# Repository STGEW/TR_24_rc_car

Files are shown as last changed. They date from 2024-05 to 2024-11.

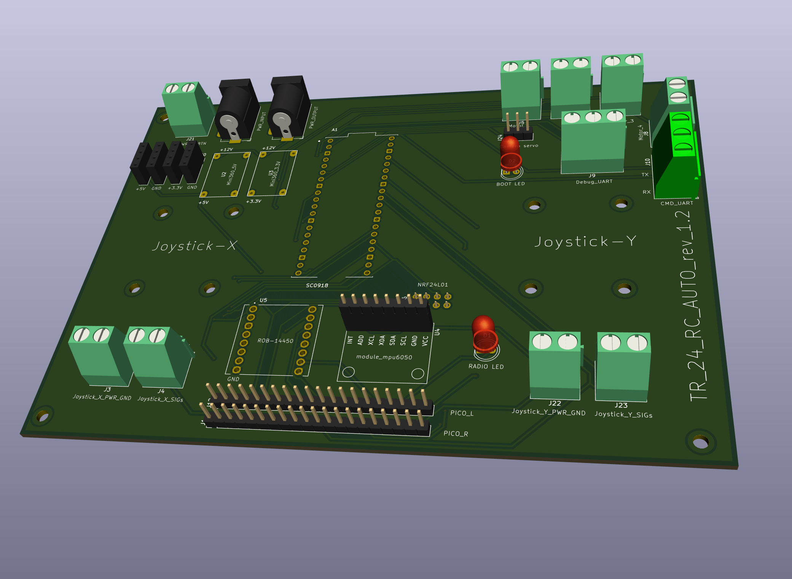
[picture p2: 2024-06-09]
pcb_design/pcb_rev_1_2_img_1.png

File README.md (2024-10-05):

# What's inside?
It's a project with a self build RC car. The project doesn't pretend to be a production ready, but is done for educational purposes.

It has two major parts - a car itself + remote controller.
The project covers:
1) a hardware design of the car and RC - PCB, components, etc
2) a software done in C (TBH it's C++, but only a tiny set of features was used) and in Micropython. They are interchangable and should work on the same set of the hardware.

# Car
A car is built on the platform ordered on the well known web site. The platform has frame done with plexiglass + 4 motos with wheels.
TBD - insert an image

# RC
RC is build with 2 joysticks. Each joystick can be moved in one direction (for the convenience).
TBD - insert an image

# Communication
Communication is done with 2 tranceivers via RF channel. A protocol is extremely simple.

# Freertos part
The code is written on C with Freertos OS. For technical details please check ./freertos_code/README.md

# BOM
Joysticks - KY-023 - 2 items
Battery for car - LiPo battery DC-12300 (12V 3000 mAh)
Batteries for RC - 4 AA type batteries. I'm using 4 Ni-MH accumulators. Can be recharged.
DC-DC converter - MINI-360 DC-DC buck converter (step down). You need 3 of them for converting input voltage to 5V or 3.3V
Motor driver - tb6612fng motor driver
MCU - Paspberry pi PICO W - 2 items (one for car, one for RC)
Motors - 4 of them, they are in a set with car frame

# PCB
Done with a Kicad. Please check ./pcb_design/car_pcb directory with project. ./pcb_design/to_factory contains gerber files generated from the project.

visual diagram done with draw.io explains in a user-friendly way how everything is connected together. - ./pcb_design/diagram.drawio

TBD - inser couple of images

# 3D models
TBD - insert couple of images

# Resources
Contains useful pdf files and images

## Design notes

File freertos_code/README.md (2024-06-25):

### Prepare environment

1) Install dependencies (example is for Ubuntu)
```shell
sudo apt install gcc-arm-none-eabi
sudo apt  install cmake
```

2) Clone freertos repo
```shell
cd /home/$USER/build/
git clone https://github.com/FreeRTOS/FreeRTOS.git
cd ./FreeRTOS
git submodule init
git submodule update --recursive
```

3) clone pico SDK (please use this document as a reference - https://datasheets.raspberrypi.com/pico/getting-started-with-pico.pdf)
```shell
mkdir /home/$USER/build
cd /home/$USER/build
mkdir ./pico
cd ./pico
git clone https://github.com/raspberrypi/pico-sdk.git --branch master
cd pico-sdk
git submodule init
git submodule update --recursive
cd ..
git clone https://github.com/raspberrypi/pico-examples.git --branch master
```

4) clone and build nRF24 driver (please use this document as a reference - https://nrf24.github.io/RF24/md_docs_2pico__sdk.html)
```shell
cd /home/$USER/build
git clone https://github.com/nRF24/RF24.git
export PICO_SDK_PATH=/home/$USER/build/pico/pico-sdk
mkdir -p /home/$USER/build/RF24/build
cd /home/$USER/build/RF24/build
cmake ../examples_pico -DCMAKE_BUILD_TYPE=Release -DPICO_BOARD=pico
cmake --build . --config Release
```

### How to build freertos C code
Inside freertos_code/car_MCU or freertos_code/rc_MCU
```shell
mkdir build
cd build
cmake .. && make
```

### Upload firmware to MCU
power off
press the boot btn
power on
you'll see in your file system a RPI storage
just drag and drop build/.uf2 file to that storage
MCU will automatically reboot and ready to go

### How to communicate with an MCU over UART
This channel is additional way to control MCU.
1) If it receives data from joystick and flag = True -> this data will be used
2) If it receives data from joystick and flag = False -> this data won't be used. Joystick will be 1 priority
3) If there is no data from joystick at all (lost connection) -> this data won't be used

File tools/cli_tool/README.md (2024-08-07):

# Tools to help test commands parser

## Python part

### Command line tool
This tool uses original C++ code of the commandsParser and allow you to communicate over UART using the protocol.

### How to run
<code>
pip install pyserial
python commands_parser_cli.py --port /dev/ttyUSB0 --br 115200
python commands_parser_cli.py --port /dev/ttyUSB1 --br 115200 --send
</code>

### Command interface

1) To set next point on the path use format: point <x float> <y float>
<code>
point 3.000 4.000
printf "\x54\x52\x08\x3f\x80\x00\x00\x40\x00\x00\x00" > /dev/ttyUSB1
</code>

2) to stop current task:
<code>
stop
</code>

## How to build everything
1) add soft links for differentialVehicleModel.cpp and differentialVehicleModel.h to the current directory
<code>
cd commands_parser
ln -s ../../freertos_code/car_MCU/commandsParser.h commandsParser.h
ln -s ../../freertos_code/car_MCU/commandsParser.cpp commandsParser.cpp
</code>

2) build commands_parser.so library:
<code>
mkdir build
cd build
cmake ..
make
cd ../
mv build/libcommands_parser.so ./commands_parser.so
</code>

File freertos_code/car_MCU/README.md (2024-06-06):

The code is written with FreeRTOS. It utilizes only 1 Core of MCU. The concept of tasks was used to design the system.

### The list of tasks

## motorDriverTask
Takes driverControlData and converts it into PWM signals for motors

## rfRxTask
Responsible for receiving data from tranceiver and sending it to the next task

## imuRawTask
Responsible for communicating with IMU module

## cameraServoControlTask
Responsible for control of the camera for RPI (done for future). 

## commandProcessorTask
Takes received from RC values and converts it into simple data for motorDriverTask. Is reponsible for timeout in case there is no signal from RC.

## main
An entry point, the place where everythin is initialized and triggered.

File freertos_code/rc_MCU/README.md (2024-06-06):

The code is written with FreeRTOS. It utilizes only 1 Core of MCU. The concept of tasks was used to design the system.

### The list of tasks

## joystickTask
Read data from joystick (ADC is used)

## rfTxTask
Responsible for transmitting the data with tranceiver

## main
An entry point, the place where everythin is initialized and triggered.

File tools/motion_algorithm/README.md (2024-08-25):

#### Build a library from cpp files
1) add soft links for differentialVehicleModel.cpp and differentialVehicleModel.h to the current directory
<code>
cd motion_algorithm
ln -s ../../freertos_code/car_MCU/differentialVehicleModel.h differentialVehicleModel.h
ln -s ../../freertos_code/car_MCU/differentialVehicleModel.cpp differentialVehicleModel.cpp
</code>

2) build differential_vehicle_model.so library:
<code>
mkdir build
cd build
cmake .. && make
mv libdifferential_vehicle_model.so ../differential_vehicle_model.so
</code>

#### Run unit tests
<code>python ./unit_tests.py</code>

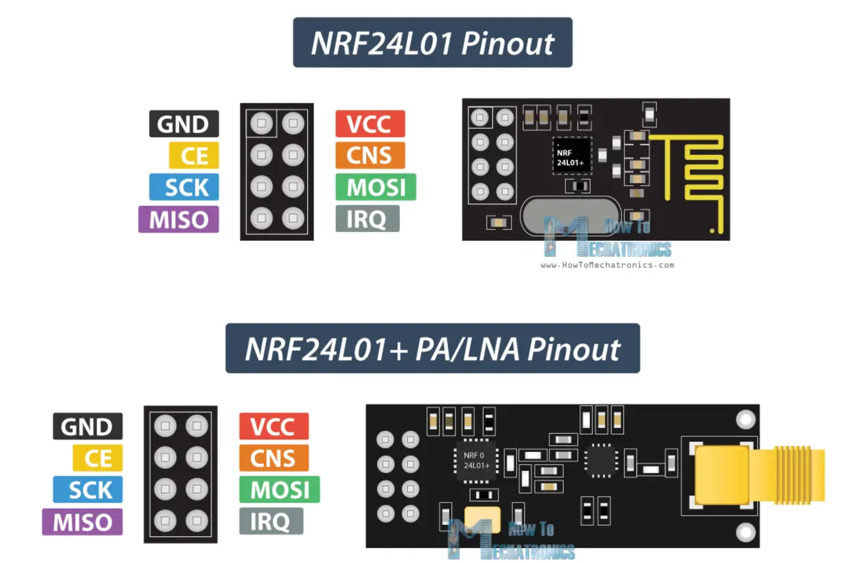
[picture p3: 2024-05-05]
resources/nrf24l01_pinout.png

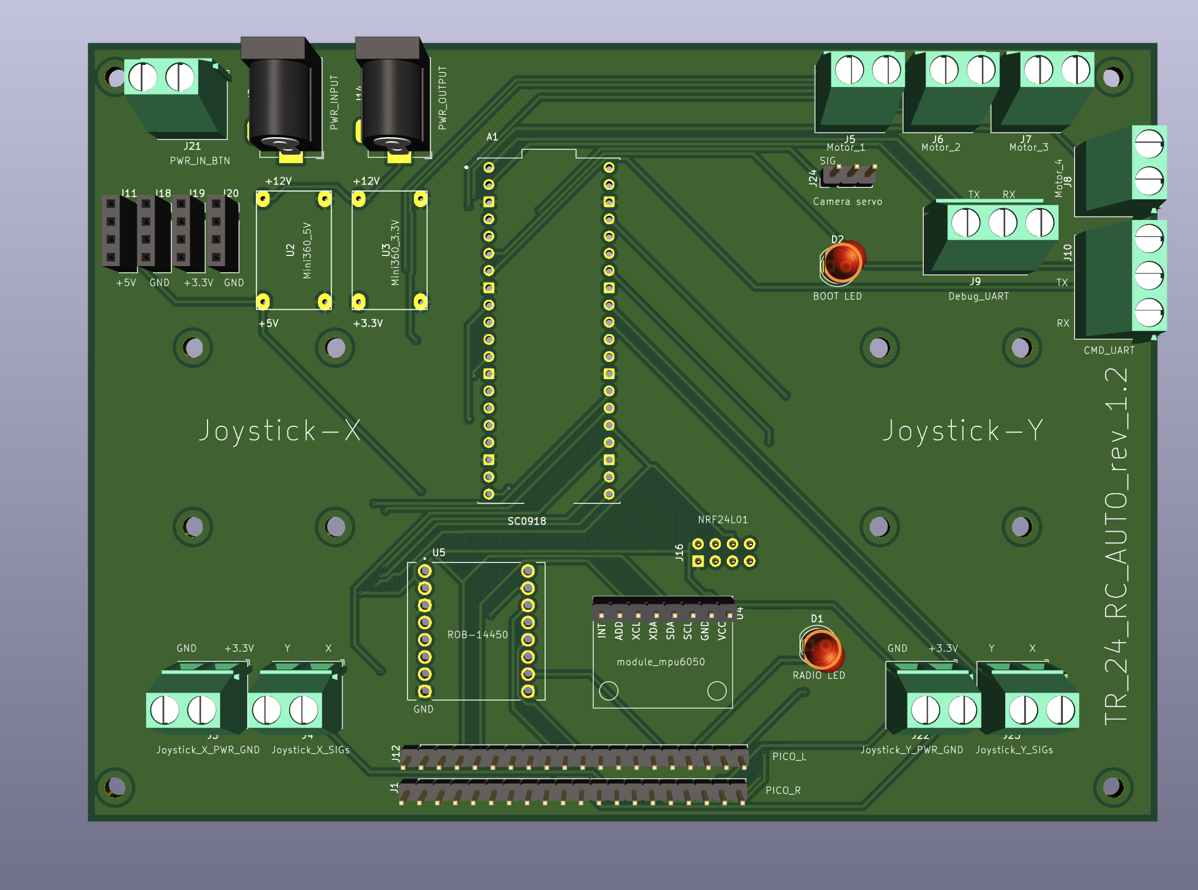
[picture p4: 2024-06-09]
pcb_design/pcb_rev_1_2_img_2.png

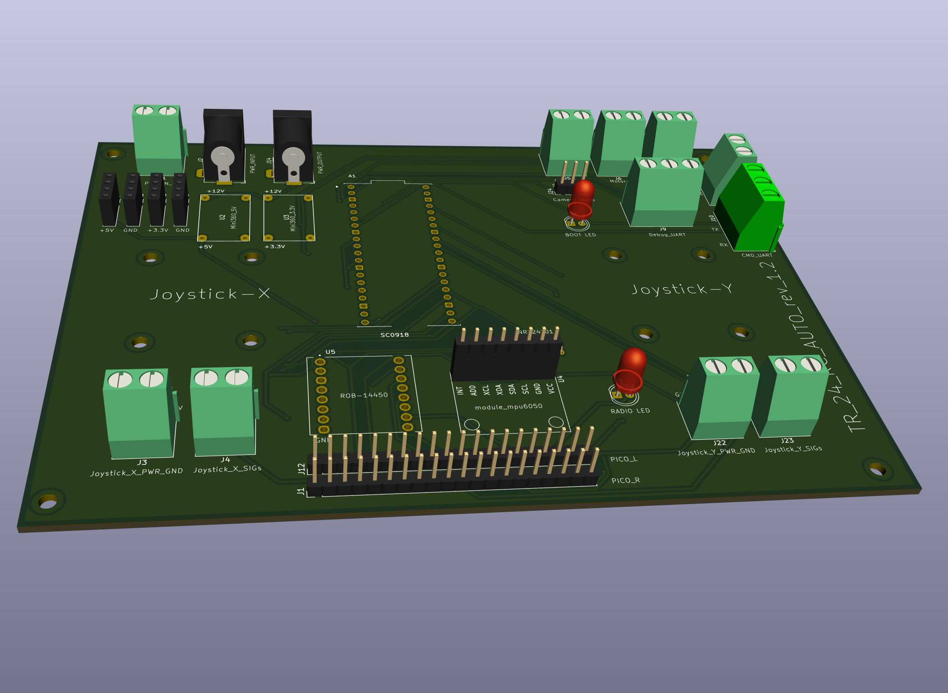
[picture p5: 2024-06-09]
pcb_design/pcb_rev_1_2_img_3.png

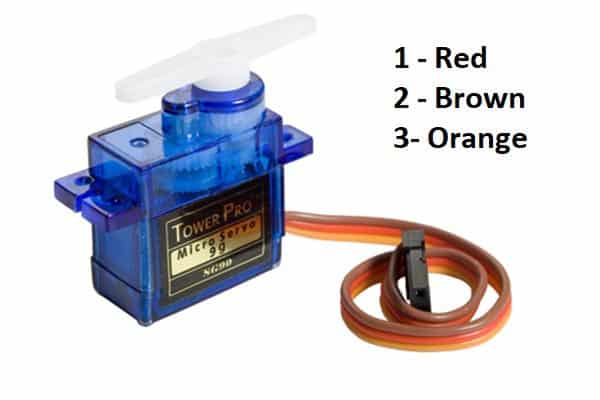
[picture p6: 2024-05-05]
resources/SG90-servo-pin-diagram.jpg

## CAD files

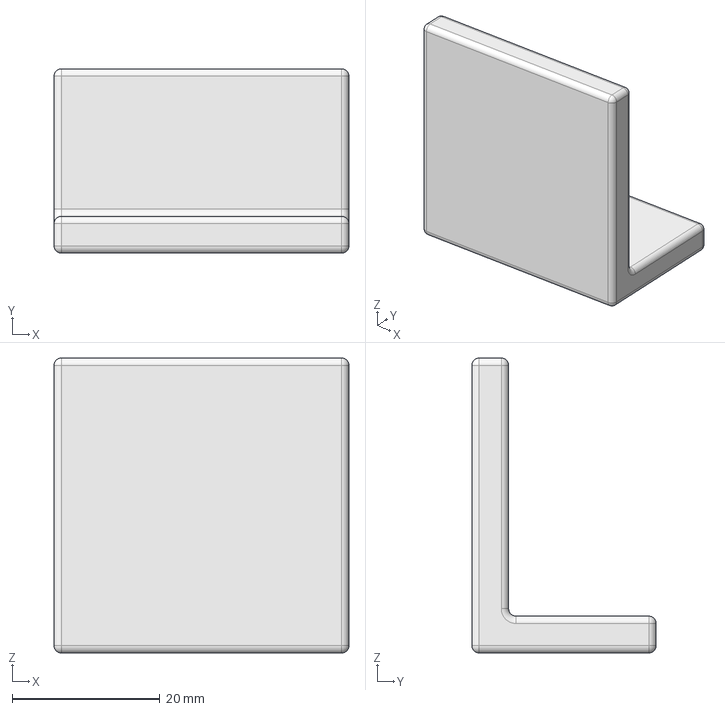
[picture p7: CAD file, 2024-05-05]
3D_models/camera_holder.FCStd
40.0 x 25.0 x 40.0 mm

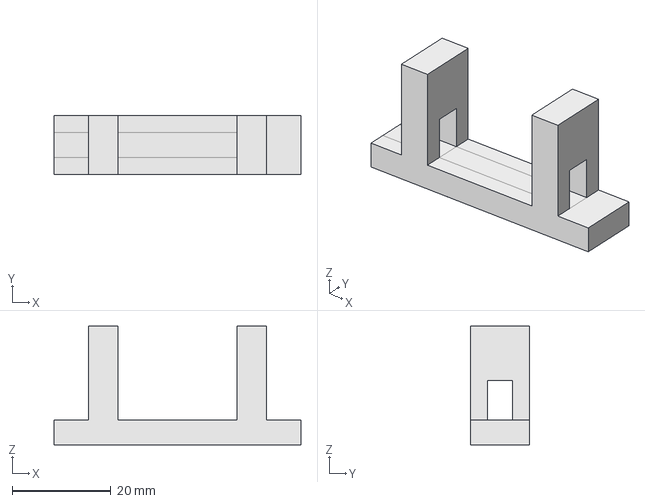
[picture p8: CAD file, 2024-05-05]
3D_models/servo_holder.FCStd
50.0 x 12.0 x 24.0 mm

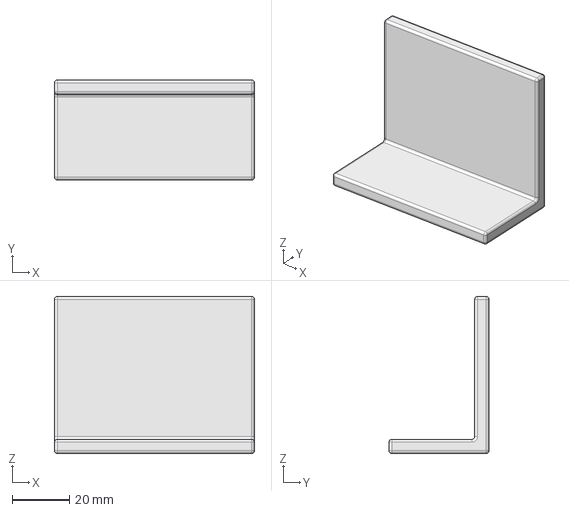
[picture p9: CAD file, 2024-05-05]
3D_models/rpi_holder.FCStd
70.0 x 35.0 x 55.0 mm

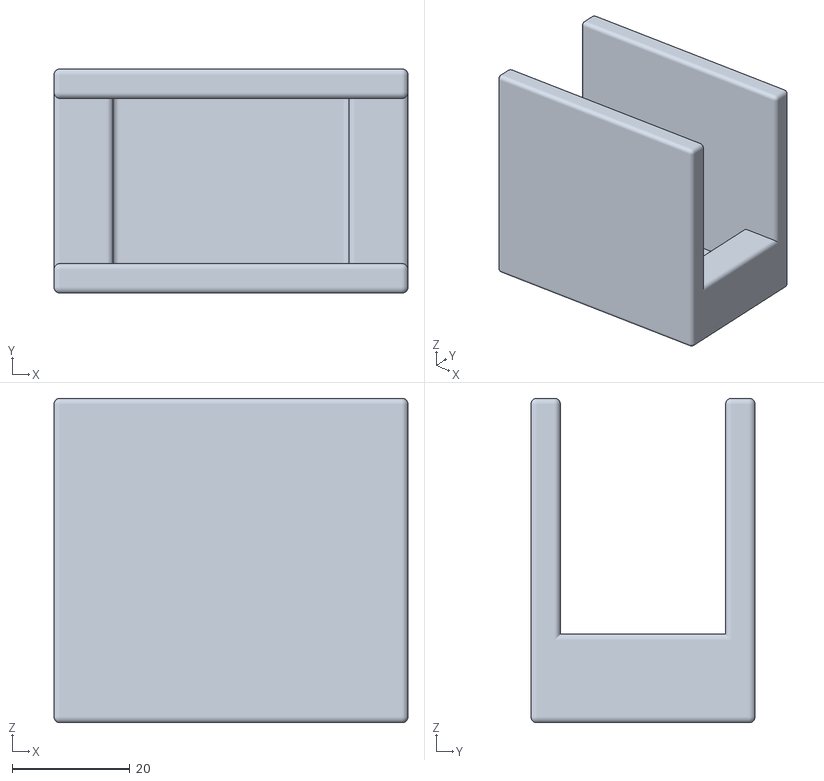
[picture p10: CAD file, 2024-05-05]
3D_models/battery_holder-Body.stl
60.0 x 38.0 x 55.0

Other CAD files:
3D_models/battery_holder.FCStd
3D_models/servo_holder-Body.stl
3D_models/rpi_holder-Body.stl
3D_models/camera_holder-Body.stl

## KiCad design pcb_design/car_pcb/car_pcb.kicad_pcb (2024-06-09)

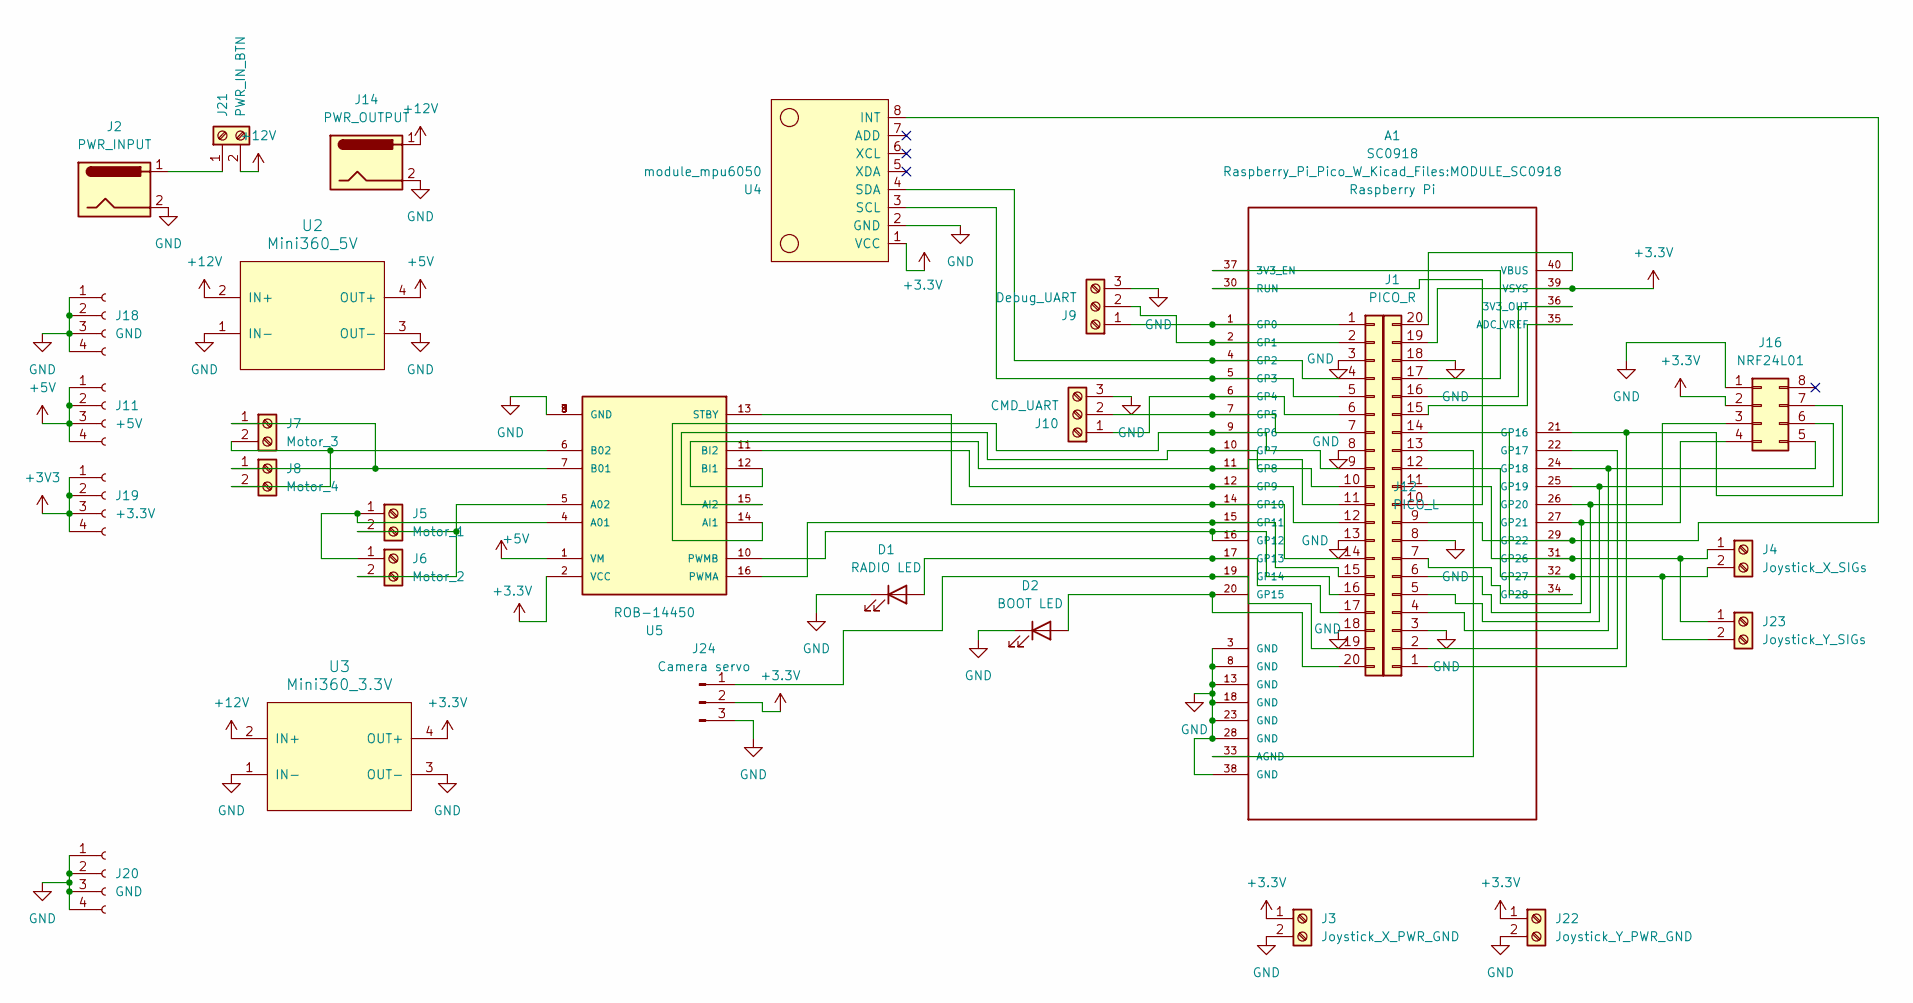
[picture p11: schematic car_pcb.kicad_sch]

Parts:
A1: SC0918; MODULE_SC0918; PARTREV 1.6
D1: RADIO LED; LED_D5.0mm
D2: BOOT LED; LED_D5.0mm
J1: PICO_R; PinHeader_1x20_P2.54mm_Vertical
J2: PWR_INPUT; BarrelJack_Horizontal
J3: Joystick_X_PWR_GND; TerminalBlock_Phoenix_MKDS-1,5-2-5.08_1x02_P5.08mm_Horizont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
J4: Joystick_X_SIGs; TerminalBlock_Phoenix_MKDS-1,5-2-5.08_1x02_P5.08mm_Horizont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
J5: Motor_1; TerminalBlock_Phoenix_MKDS-1,5-2-5.08_1x02_P5.08mm_Horizont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
J6: Motor_2; TerminalBlock_Phoenix_MKDS-1,5-2-5.08_1x02_P5.08mm_Horizont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
J7: Motor_3; TerminalBlock_Phoenix_MKDS-1,5-2-5.08_1x02_P5.08mm_Horizont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
J8: Motor_4; TerminalBlock_Phoenix_MKDS-1,5-2-5.08_1x02_P5.08mm_Horizont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
J9: Debug_UART; TerminalBlock_Phoenix_MKDS-1,5-3-5.08_1x03_P5.08mm_Horizont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
J10: CMD_UART; TerminalBlock_Phoenix_MKDS-1,5-3-5.08_1x03_P5.08mm_Horizont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
J11: +5V; PinSocket_1x04_P2.54mm_Vertical
J12: PICO_L; PinHeader_1x20_P2.54mm_Vertical
J14: PWR_OUTPUT; BarrelJack_Horizontal
J16: NRF24L01; PinSocket_2x04_P2.54mm_Vertical
J18, J20: GND; PinSocket_1x04_P2.54mm_Vertical
J19: +3.3V; PinSocket_1x04_P2.54mm_Vertical
J21: PWR_IN_BTN; TerminalBlock_Phoenix_MKDS-1,5-2-5.08_1x02_P5.08mm_Horizont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
J22: Joystick_Y_PWR_GND; TerminalBlock_Phoenix_MKDS-1,5-2-5.08_1x02_P5.08mm_Horizont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
J23: Joystick_Y_SIGs; TerminalBlock_Phoenix_MKDS-1,5-2-5.08_1x02_P5.08mm_Horizont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
J24: Camera servo; PinHeader_1x03_P2.54mm_Vertical
U2: Mini360_5V; Mini360_step-down
U3: Mini360_3.3V; Mini360_step-down
U4: module_mpu6050
U5: ROB-14450; MODULE_ROB-14450; PARTREV 11-13-17

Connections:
+3.3V: A1.39 (VSYS), J1.19, J3.1, J16.2, J22.1, J24.2, U3.4 (OUT+), U4.1 (VCC), U5.2 (VCC)
+3V3: J19.1, J19.2, J19.3, J19.4
+5V: J11.1, J11.2, J11.3, J11.4, U2.4 (OUT+), U5.1 (VM)
+12V: J14.1, J21.2, U2.2 (IN+), U3.2 (IN+)
GND: A1.3 (GND), A1.8 (GND), A1.13 (GND), A1.18 (GND), A1.23 (GND), A1.28 (GND), A1.38 (GND), D1.1 (K), D2.1 (K), J1.3, J1.8, J1.18, J2.2, J3.2, J9.3, J10.3, J12.3, J12.8, J12.13, J12.18, J14.2, J16.1, J18.1, J18.2, J18.3, J18.4, J20.1, J20.2, J20.3, J20.4, J22.2, J24.3, U2.1 (IN-), U2.3 (OUT-), U3.1 (IN-), U3.3 (OUT-), U4.2 (GND), U5.3 (GND), U5.8 (GND), U5.9 (GND)
unnamed: A1.37 (3V3_EN), J1.17
unnamed: A1.36 (3V3_OUT), J1.16
unnamed: A1.35 (ADC_VREF), J1.15
unnamed: A1.33 (AGND), J1.13
unnamed: A1.1 (GP0), J9.1, J12.1
unnamed: A1.2 (GP1), J9.2, J12.2
unnamed: A1.4 (GP2), J12.4, U4.4 (SDA)
unnamed: A1.5 (GP3), J12.5, U4.3 (SCL)
unnamed: A1.6 (GP4), J10.1, J12.6
unnamed: A1.7 (GP5), J10.2, J12.7
unnamed: A1.9 (GP6), J12.9, U5.14 (AI1)
unnamed: A1.10 (GP7), J12.10, U5.15 (AI2)
unnamed: A1.11 (GP8), J12.11, U5.12 (BI1)
unnamed: A1.12 (GP9), J12.12, U5.11 (BI2)
unnamed: A1.14 (GP10), J12.14, U5.13 (STBY)
unnamed: A1.15 (GP11), J12.15, U5.16 (PWMA)
unnamed: A1.16 (GP12), J12.16, U5.10 (PWMB)
unnamed: A1.17 (GP13), D1.2 (A), J12.17
unnamed: A1.19 (GP14), J12.19, J24.1
unnamed: A1.20 (GP15), D2.2 (A), J12.20
unnamed: A1.21 (GP16), J1.1, J16.7
unnamed: A1.22 (GP17), J1.2
unnamed: A1.24 (GP18), J1.4, J16.5
unnamed: A1.25 (GP19), J1.5, J16.6
unnamed: A1.26 (GP20), J1.6, J16.3
unnamed: A1.27 (GP21), J1.7, J16.4
unnamed: A1.29 (GP22), J1.9, U4.8 (INT)
unnamed: A1.31 (GP26), J1.11, J4.1, J23.1
unnamed: A1.32 (GP27), J1.12, J4.2, J23.2
unnamed: A1.34 (GP28), J1.14
unnamed: A1.30 (RUN), J1.10
unnamed: A1.40 (VBUS), J1.20
unnamed: J5.1, J6.1, U5.4 (A01)
unnamed: J5.2, J6.2, U5.5 (A02)
unnamed: J7.1, J8.1, U5.7 (B01)
unnamed: J7.2, J8.2, U5.6 (B02)
unnamed: J2.1, J21.1

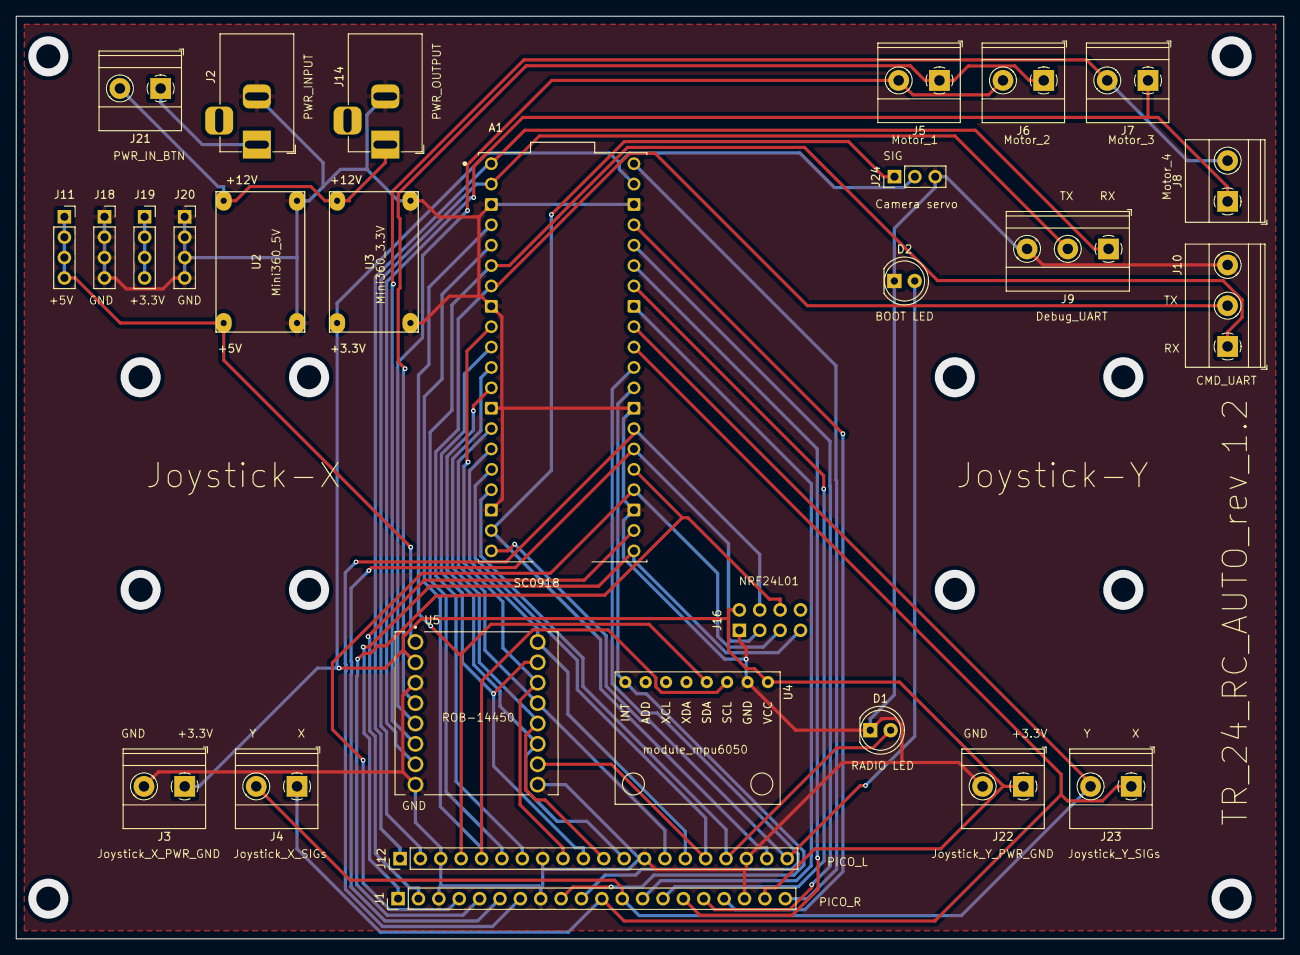
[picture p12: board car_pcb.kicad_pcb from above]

Board: 2 copper layers, 158.0 x 115.0 mm, 28 parts (1 on the bottom side), 42 nets.

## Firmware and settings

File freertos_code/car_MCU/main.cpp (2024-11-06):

/* Scheduler include files. */
#include "FreeRTOS.h"
#include "task.h"
#include "semphr.h"

#include "TimerDemo.h"
#include "QueueOverwrite.h"
#include "EventGroupsDemo.h"
#include "IntSemTest.h"
#include "TaskNotify.h"

#include "controlArbiterTask.h"
#include "cameraServoTask.h"
#include "hardware/gpio.h"
#include "odometerTask.h"
#include "uartHandlerTask.h"
#include "imuRawTask.h"


#include "../const.h"

/* Library includes. */
#include <stdio.h>
#include "pico/stdlib.h"
#if ( mainRUN_ON_CORE == 1 )
#include "pico/multicore.h"
#endif

/*-----------------------------------------------------------*/
// motorDriverTask functions
extern void setupMotorDriver( void );

// controlArbiterTask functions
extern void setupControlArbiterTask( void );
extern void runControlArbiterTask( void *pvParameters );

// imuRawTask functions
extern void setupIMURawTask();
extern void runIMURawTask( void *pvParameters );

// cameraServoControlTask functions
extern void setupCameraServoTask();
extern void runCameraServoTask( void *pvParameters );

// uartHandlerTask functions
extern void setupUartHandlerHardware();
extern void runUartHandlerTask(void *pvParameters);

// odometerTask functions
extern TaskHandle_t xOdometerLeftTaskHandle;
extern TaskHandle_t xOdometerRightTaskHandle;
extern void setupOdometerTask();
extern void runOdometerLeftTask(void *pvParameters );
extern void runOdometerRightTask(void *pvParameters );

static void prvSetupHardware( void );

/* Prototypes for the standard FreeRTOS callback/hook functions implemented
within this file. */
void vApplicationMallocFailedHook( void );
void vApplicationIdleHook( void );
void vApplicationStackOverflowHook( TaskHandle_t pxTask, char *pcTaskName );
void vApplicationTickHook( void );
/*-----------------------------------------------------------*/

void core_1_tasks( void )
{

    cameraServoSemaphore = xSemaphoreCreateBinary();
    odometerMutex = xSemaphoreCreateMutex();
    imuMutex = xSemaphoreCreateMutex();
    uartStopCMDMutex = xSemaphoreCreateMutex();

    // Working with UART queues
    // To send something to UART
    q_uart_tx = xQueueCreate(10, sizeof(char*));
    if (NULL == q_uart_tx) {
        printf("ERROR! q_uart_tx can't be created\n");
        return;
    }

    // To read points from UART
    q_target_point_2D = xQueueCreate(10, sizeof(Point2D));
    if (NULL == q_target_point_2D) {
        printf("ERROR! q_target_point_2D can't be created\n");
        return;
    }

    // these are positions (x,y,phi) of the car
    q_car_pos = xQueueCreate(20, sizeof(Vehicle2DPosition));
    if (NULL == q_car_pos) {
        printf("ERROR! q_car_pos can't be created\n");
        return;
    }    

    xTaskCreate( runControlArbiterTask, "runControlArbiterTask",
        configMINIMAL_STACK_SIZE, NULL, tskIDLE_PRIORITY + 1, NULL );

    xTaskCreate( runIMURawTask, "imuRawTask",
        configMINIMAL_STACK_SIZE, NULL, tskIDLE_PRIORITY + 1, NULL );

    // xTaskCreate( runCameraServoTask, "cameraServoTask",                     
    //     configMINIMAL_STACK_SIZE, NULL, tskIDLE_PRIORITY + 1, NULL );

    xTaskCreate( runUartHandlerTask, "runUartHandlerTask",                     
        configMINIMAL_STACK_SIZE, NULL, tskIDLE_PRIORITY + 1, NULL );

    xTaskCreate(runOdometerLeftTask, "runOdometerLeftTask",
        configMINIMAL_STACK_SIZE, NULL, tskIDLE_PRIORITY + 1,
        &xOdometerLeftTaskHandle);

    xTaskCreate(runOdometerRightTask, "runOdometerRightTask",
        configMINIMAL_STACK_SIZE, NULL, tskIDLE_PRIORITY + 1,
        &xOdometerRightTaskHandle);

    vTaskStartScheduler();

    for( ;; );
}

int main( void )
{
    /* Configure the hardware ready to run the demo. */
    prvSetupHardware();
    const char *rtos_name = "FreeRTOS SMP";
    core_1_tasks();
    // Launch FreeRTOS on core 0 and core 1
    // multicore_launch_core1(core_1_tasks);
    return 0;
}
/*-----------------------------------------------------------*/

static void prvSetupHardware( void )
{
    stdio_init_all();
    // By default uart 0 has BR 115200, we want it to be higher
    uart_init(UART_LOG_ID, UART_LOG_BAUD_RATE);
    gpio_set_function(UART_LOG_TX_PIN, GPIO_FUNC_UART);
    gpio_set_function(UART_LOG_RX_PIN, GPIO_FUNC_UART);
    uart_puts(uart0, "RC car is ready\n");

    setupMotorDriver();
    setupIMURawTask();
    setupControlArbiterTask();
    setupUartHandlerHardware();
    setupCameraServoTask();
    setupOdometerTask();

    gpio_init(BOOT_LED_PIN);
    gpio_set_dir(BOOT_LED_PIN, GPIO_OUT);
    gpio_put(BOOT_LED_PIN, 1);
}
/*-----------------------------------------------------------*/

void vApplicationMallocFailedHook( void )
{
    /* Called if a call to pvPortMalloc() fails because there is insufficient
    free memory available in the FreeRTOS heap.  pvPortMalloc() is called
    internally by FreeRTOS API functions that create tasks, queues, software
    timers, and semaphores.  The size of the FreeRTOS heap is set by the
    configTOTAL_HEAP_SIZE configuration constant in FreeRTOSConfig.h. */

    /* Force an assert. */
    configASSERT( ( volatile void * ) NULL );
}
/*-----------------------------------------------------------*/

void vApplicationStackOverflowHook( TaskHandle_t pxTask, char *pcTaskName )
{
    ( void ) pcTaskName;
    ( void ) pxTask;

    /* Run time stack overflow checking is performed if
    configCHECK_FOR_STACK_OVERFLOW is defined to 1 or 2.  This hook
    function is called if a stack overflow is detected. */

    /* Force an assert. */
    configASSERT( ( volatile void * ) NULL );
}
/*-----------------------------------------------------------*/

void vApplicationIdleHook( void )
{
    volatile size_t xFreeHeapSpace;

    /* This is just a trivial example of an idle hook.  It is called on each
    cycle of the idle task.  It must *NOT* attempt to block.  In this case the
    idle task just queries the amount of FreeRTOS heap that remains.  See the
    memory management section on the http://www.FreeRTOS.org web site for memory
    management options.  If there is a lot of heap memory free then the
    configTOTAL_HEAP_SIZE value in FreeRTOSConfig.h can be reduced to free up
    RAM. */
    xFreeHeapSpace = xPortGetFreeHeapSize();

    /* Remove compiler warning about xFreeHeapSpace being set but never used. */
    ( void ) xFreeHeapSpace;
}
/*-----------------------------------------------------------*/

void vApplicationTickHook( void )
{
}

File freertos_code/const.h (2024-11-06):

#pragma once

#include <stdint.h>

#define mainRUN_ON_CORE 1

#define UART_LOG_TX_PIN     0
#define UART_LOG_RX_PIN     1
#define IMU_I2C_SDA_PIN     2
#define IMU_I2C_SCL_PIN     3
#define UART_CTRL_TX_PIN    4
#define UART_CTRL_RX_PIN    5
#define AI1_PIN             6
#define AI2_PIN             7
#define BI1_PIN             8
#define BI2_PIN             9
#define STBY_PIN            10
#define PWM_A_PIN           11
#define PWM_B_PIN           12
#define RADIO_LED_PIN       13
#define CAMERA_SERVO_PIN    14
#define JOY_EXT_CTRL_PIN    14
#define BOOT_LED_PIN        15
#define CE_PIN              20
#define CSN_PIN             21
#define X_AXIS_PIN          26
#define Y_AXIS_PIN          27
#define ODOMETER_LEFT_PIN   26
#define ODOMETER_RIGHT_PIN  27

#define ADC_CHANNEL_X       0
#define ADC_CHANNEL_Y       1

#define UART_CTRL_ID        uart1
#define UART_CTRL_BAUD_RATE 460800

#define UART_LOG_ID        uart0
#define UART_LOG_BAUD_RATE 460800

// contains raw measurements from joystick
struct __attribute__((__packed__)) JoystickRawData {
    uint32_t x;
    uint32_t y;
    bool ext_control;
};

// left -100 ... 100
// right -100 ... 100
struct __attribute__((__packed__)) EnginesPwr {
    int32_t left;
    int32_t right;
};

// Driver data
// duty cycle 0 .. 65 535
struct DriverControlData {
    int direction_A;
    int direction_B;
    int duty_cycle_A;
    int duty_cycle_B;
};

// ODOMETER
// describes the count of holes in used for odometer disk
#define ODOMETER_COUNT_OF_HOLES_IN_DISK     40
// #define ODOMETER_COUNT_OF_HOLES_IN_DISK     20
#define WHEEL_DIAMETER_M                    0.064
#define VEHICLE_BASE_SIZE_M                 0.195

struct __attribute__((__packed__)) Point2D {
    float x;
    float y;
};

struct __attribute__((__packed__)) Vehicle2DPosition {
    Point2D p;
    float phi;
};

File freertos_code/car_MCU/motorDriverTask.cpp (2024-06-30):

#include "FreeRTOS.h"
#include "pico/stdlib.h"
#include "hardware/pwm.h"
#include "motorDriverTask.h"
#include <stdio.h>


// semaphore for reading driver control
SemaphoreHandle_t motorDriverSemaphore;
// contains values for driver
struct DriverControlData driver = {OFF, OFF, 0, 0};


void setMotorDirection(int I1_PIN, int I2_PIN, int direction) {
    switch (direction) {
        case FORWARD:
            gpio_put(I1_PIN, 1);
            gpio_put(I2_PIN, 0);
            break;
        case OFF:
            gpio_put(I1_PIN, 0);
            gpio_put(I2_PIN, 0);
            break ;
        case REVERSE:
            gpio_put(I1_PIN, 0);
            gpio_put(I2_PIN, 1);
            break;
        case BRAKE:
            gpio_put(I1_PIN, 1);
            gpio_put(I2_PIN, 1);
            break;
        default:
            printf("For motor direction unknown value arrived: %d\n", direction);
            break;
    }
}


void pwm_init_pin(uint8_t pin) {
    gpio_set_function(pin, GPIO_FUNC_PWM);
    uint slice_num = pwm_gpio_to_slice_num(pin);
    pwm_config config = pwm_get_default_config();
    pwm_config_set_clkdiv(&config, 4.f);
    pwm_init(slice_num, &config, true);
}


// initialize required for motor pins
void setupMotorDriverTask( void )
{
    // intially OFF
    gpio_init(AI1_PIN);
    gpio_init(AI2_PIN);
    gpio_set_dir(AI1_PIN, GPIO_OUT);
    gpio_set_dir(AI2_PIN, GPIO_OUT);
    setMotorDirection(AI1_PIN, AI2_PIN, OFF);

    gpio_init(BI1_PIN);
    gpio_init(BI2_PIN);
    gpio_set_dir(BI1_PIN, GPIO_OUT);
    gpio_set_dir(BI2_PIN, GPIO_OUT);
    setMotorDirection(BI1_PIN, BI2_PIN, OFF);

    // STDBY is always ON
    gpio_init(STBY_PIN);
    gpio_set_dir(STBY_PIN, GPIO_OUT);
    gpio_put(STBY_PIN, 1);

    // setup PWM A and PWM B
    pwm_init_pin(PWM_A_PIN);
    pwm_init_pin(PWM_B_PIN);
}


void runMotorDriverTask( void *pvParameters )
{

    TickType_t xNextWakeTime;
    const unsigned long ulValueToSend = 100UL;

    /* Remove compiler warning about unused parameter. */
    ( void ) pvParameters;

    /* Initialise xNextWakeTime - this only needs to be done once. */
    xNextWakeTime = xTaskGetTickCount();

    setMotorDirection(AI1_PIN, AI2_PIN, OFF);
    setMotorDirection(BI1_PIN, BI2_PIN, OFF);
    
    for( ;; )
    {
        if (xSemaphoreTake(motorDriverSemaphore, 0) == pdTRUE) {
            // printf(
            //     "motor A direction is: %d duty cycle: %d\n",
            //     driver.direction_A,
            //     driver.duty_cycle_A);

            setMotorDirection(AI1_PIN, AI2_PIN, driver.direction_A);
            pwm_set_gpio_level(
                PWM_A_PIN, driver.duty_cycle_A);

            // printf(
            //     "motor B direction is: %d duty cycle: %d\n",
            //     driver.direction_B,
            //     driver.duty_cycle_B);

            setMotorDirection(BI1_PIN, BI2_PIN, driver.direction_B);
            pwm_set_gpio_level(
                PWM_B_PIN, driver.duty_cycle_B);
        } else {
            // printf("motorDriverTask didn't get a semaphore \n");
        }
        
        // 10 msec delay ~ 100 Hz
        vTaskDelay(pdMS_TO_TICKS( 10 ));
    }
}

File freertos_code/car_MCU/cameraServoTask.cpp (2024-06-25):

#include <stdio.h>
#include "cameraServoTask.h"
#include "hardware/pwm.h"
#include "pico/stdlib.h"
#include "../const.h"


// variables to communicate with task
int cameraAngle = 90;
SemaphoreHandle_t cameraServoSemaphore;


uint16_t calc_duty_from_angle(int angle) {
    // some magic numbers. I was unable to calculate it in a proper way
    return (uint16_t) (180 + (1456 - 180) * angle / 180);
}


void setupCameraServoTask() {
    // Configure PWM settings
    gpio_set_function(CAMERA_SERVO_PIN, GPIO_FUNC_PWM);

    uint slice_num = pwm_gpio_to_slice_num(CAMERA_SERVO_PIN);
    printf("Camera servo task slice: %u\n", slice_num);
    
    pwm_config config = pwm_get_default_config();
    
    // Set clock divider to achieve desired PWM frequency
    // Formula: PWM clock frequency = sysclock / (divider + 1)
    // For 50 Hz, PWM clock frequency = 125 MHz / (2499 + 1) = 50 kHz
    pwm_config_set_clkdiv(&config, 2499); // 2499 + 1 = 2500
    
    // Set counter wrap value for desired PWM period
    // Formula: PWM period = (wrap + 1) / PWM clock frequency
    // For 50 Hz, PWM period = (2500 + 1) / 50 kHz = 0.02 seconds = 20 ms
    pwm_config_set_wrap(&config, 2500); // 2500 + 1 = 2501

    // Initialize PWM
    pwm_init(slice_num, &config, true);

    uint16_t duty = calc_duty_from_angle(cameraAngle);
    pwm_set_gpio_level(CAMERA_SERVO_PIN, duty);
}


void runCameraServoTask( void *pvParameters ) {
    for( ;; )
    {
        if (xSemaphoreTake(cameraServoSemaphore, 0) == pdTRUE) {
            printf("Camera new angle to set: %d\n", cameraAngle);
            uint16_t duty = calc_duty_from_angle(cameraAngle);
            pwm_set_gpio_level(CAMERA_SERVO_PIN, duty);
        }
        // 10 msec delay ~ 100 Hz
        vTaskDelay(pdMS_TO_TICKS( 10 ));
    }
}

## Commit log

2024-05-05 add 3D models
    [battery_holder-Body.stl, battery_holder.FCStd, camera_holder-Body.stl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]
2024-05-05 add pcb design
    [car_pcb-B_Cu.gbl, car_pcb-B_Mask.gbs, car_pcb-B_Paste.gbp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]
2024-05-17 update pcbs
    [car_pcb-B_Cu.gbl, car_pcb-B_Mask.gbs, car_pcb-B_Paste.gbp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]
2024-06-05 fix build system and fix differences in pins between RC and AUTO
    [joystickTask.cpp, main.cpp, rfTxTask.cpp]
2024-06-09 fix issue with mistakes in rev 1.1. Now rev 1.2 is ready
    [car_pcb-B_Cu.gbl, car_pcb-B_Mask.gbs, car_pcb-B_Paste.gbp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]
2024-06-09 fix a bug with wrong BRAKE code
    [motorDriverTask.cpp]
2024-07-12 add pid controller class
2024-07-16 fix odometer part, fix bugs
    [const.h, imuRawTask.cpp, odometerTask.cpp]
2024-08-20 fix odometry
2024-09-03 support message with odometry
2024-09-19 Fix issue with not initialized pointer change frequency of the PV msg Output PV msg only during several states
    [autonomousMode.cpp, controlArbiterTask.cpp, uartHandlerTask.cpp]
2024-11-06 Manually initialize UART0 for car and rc Change UART0 baudrate from the default value 115200 to more logical 460800 for car and rc
